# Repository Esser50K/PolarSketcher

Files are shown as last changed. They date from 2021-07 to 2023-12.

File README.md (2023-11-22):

# Polar Sketcher

The polar Sketcher is a somewhat compact robotic arm plotter.

The motivation is to have a somewhat simple and cheap design to create a 2D plotter.
It is also meant to not occupy a lot of space when idle as you don't need an entire XY CNC setup.

## Demo Video

Take a look a the journey of this build (without looking at commits)
https://youtu.be/corrBt9IMOM

## Upload PolarSketcherFirmware

The firmware of this project is designed to run on an esp32.
To upload the code from the command line run the following command from the `PolarSketcherFirmware` directory:
> platformio run --target upload --environment uno

You may want to change the `serial_port` option in the `platformio.ini` file. The current one is meant for the raspberrypi when using the GPIO serial connection.

To download platformio in the first place run:

`
curl -fsSL
     -o get-platformio.py
     https://raw.githubusercontent.com/platformio/platformio-core-installer/master/get-platformio.py
`

`python3 get-platformio.py`

## Optional software

There is a feature still in development to allow for the storing of drawings in order to pick up where you left off.
for this a local mongoDB is needed, for development se this to run mongodb locally:
> docker run -p 27017:27017 -v $PWD/mongodb:/data/db mongo:latest

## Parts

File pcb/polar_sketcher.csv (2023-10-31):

Id | Designator | Package | Quantity | Designation | Supplier and ref
1 | C2,C1 | CP_Radial_D8.0mm_P5.00mm | 2 | 100u
2 | A2,A1 | Pololu_Breakout-16_15.2x20.3mm | 2 | Pololu_Breakout_A4988
3 | R4,R2,R1,R3 | R_Axial_DIN0207_L6.3mm_D2.5mm_P7.62mm_Horizontal | 4 | 330
4 | J11 | PinHeader_1x05_P2.54mm_Vertical | 1 | ENCODER
5 | J5 | PinSocket_1x15_P2.54mm_Vertical | 1 | ESP_H_2
6 | J4 | PinSocket_1x15_P2.54mm_Vertical | 1 | ESP_H_1
7 | J8 | PinHeader_1x04_P2.54mm_Vertical | 1 | STEPPER_2
8 | J9 | PinHeader_1x02_P2.54mm_Vertical | 1 | MOTOR_POWER
9 | J3 | PinHeader_1x04_P2.54mm_Vertical | 1 | STEPPER_1
10 | J7 | PinHeader_1x02_P2.54mm_Vertical | 1 | LIMIT_4
11 | J6 | PinHeader_1x02_P2.54mm_Vertical | 1 | LIMIT_2
12 | J2 | PinHeader_1x02_P2.54mm_Vertical | 1 | LIMIT_3
13 | J1 | PinHeader_1x02_P2.54mm_Vertical | 1 | LIMIT_1
14 | J10 | PinHeader_1x03_P2.54mm_Vertical | 1 | SERVO_PINS

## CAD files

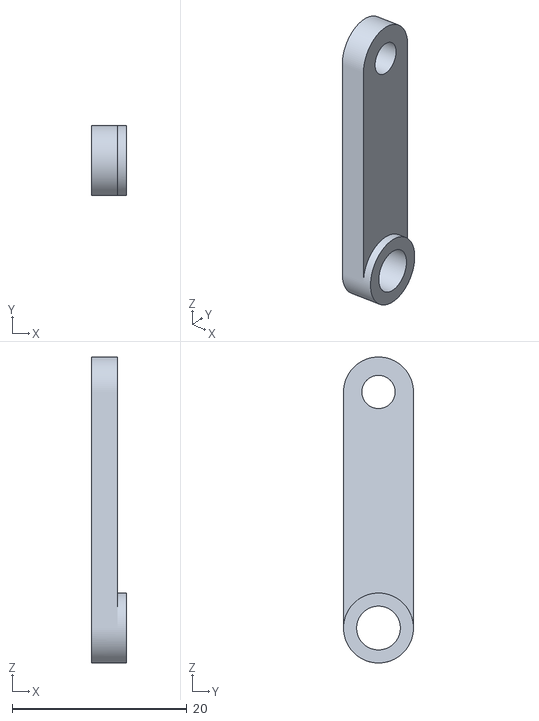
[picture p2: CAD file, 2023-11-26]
models/ServoLink2.stl
4.00 x 8.00 x 35.0

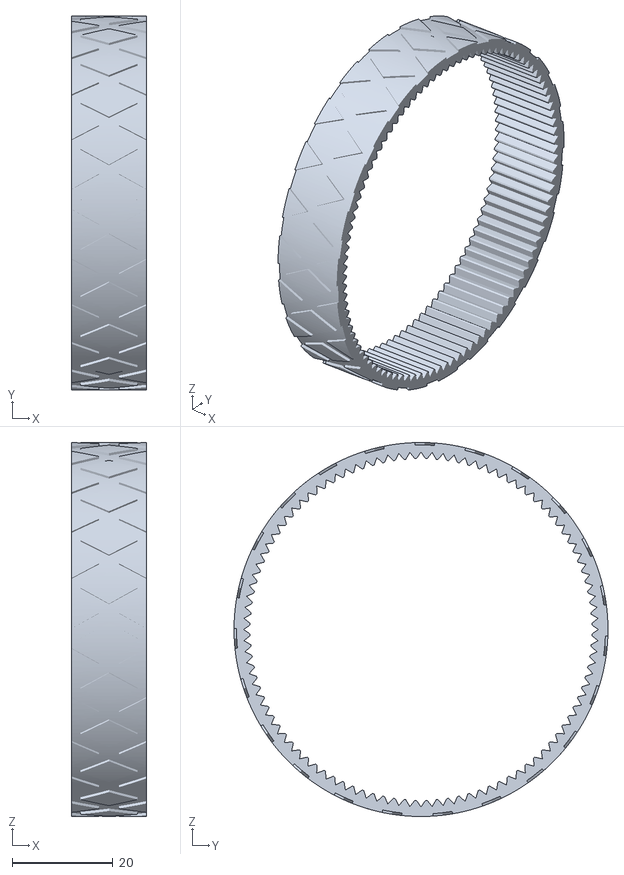
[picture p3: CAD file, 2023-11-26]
models/EndTire.stl
15.0 x 74.4 x 74.4

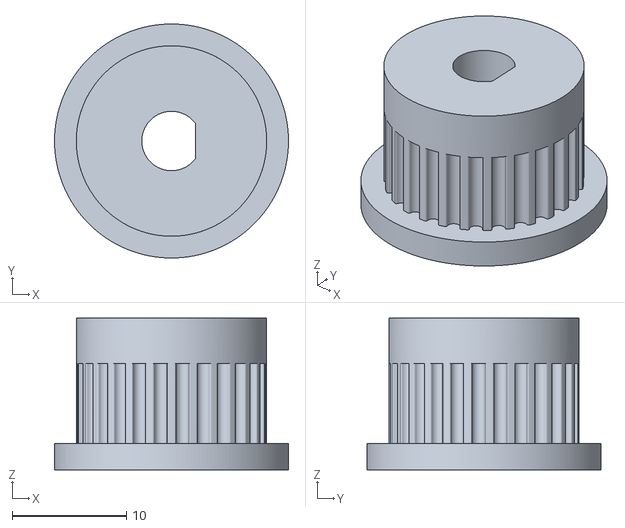
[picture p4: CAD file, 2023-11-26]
models/lil_pulley.stl
20.5 x 20.5 x 13.3

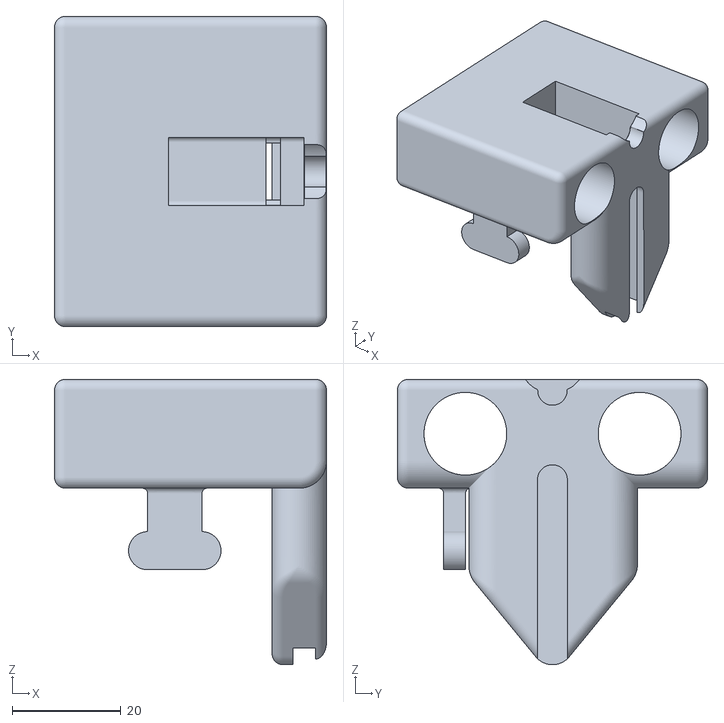
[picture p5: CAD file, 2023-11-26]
models/Carriage.stl
50.0 x 57.0 x 52.5

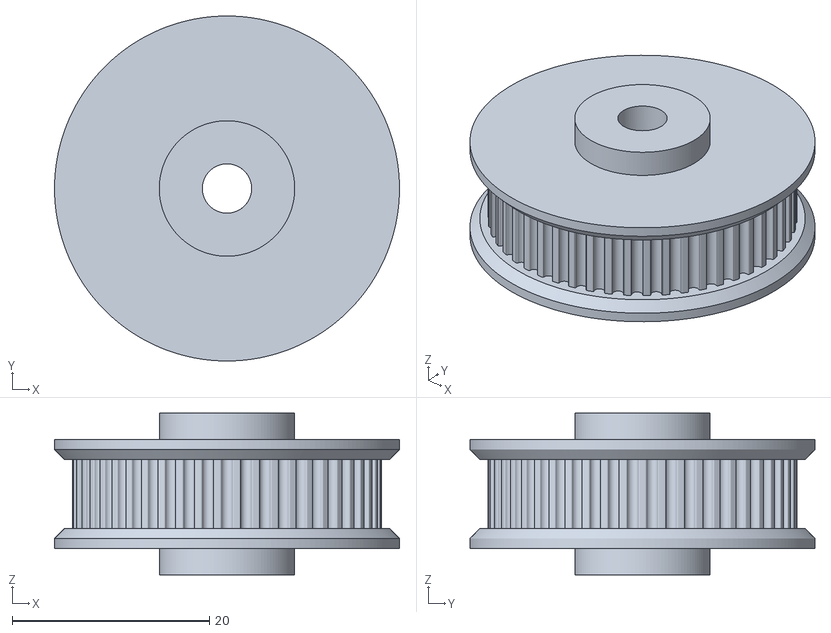
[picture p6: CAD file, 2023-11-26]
models/EndTensioner.stl
35.0 x 35.0 x 16.4

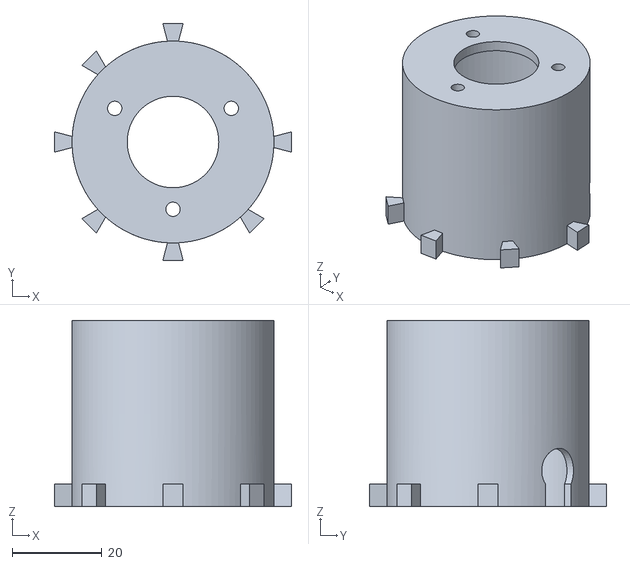
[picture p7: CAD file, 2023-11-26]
models/EncoderHousingTop.stl
52.8 x 52.8 x 41.5

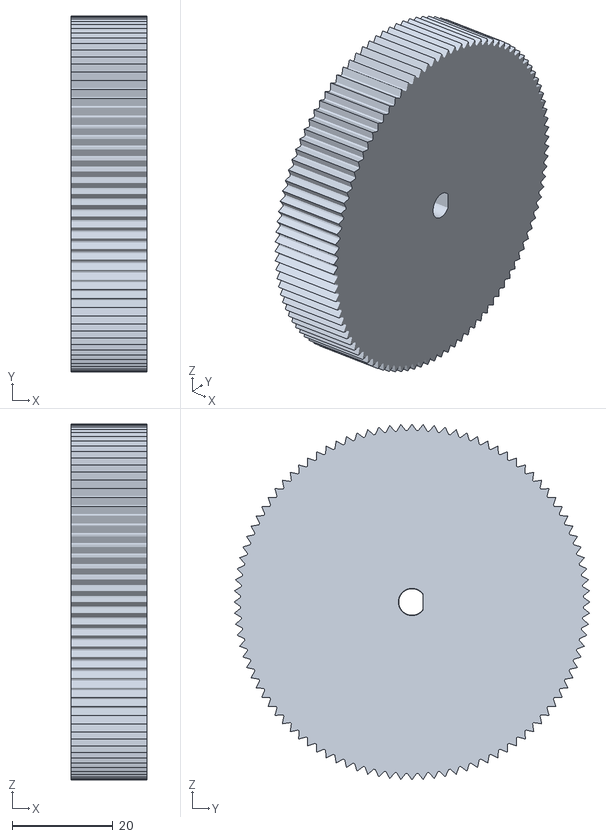
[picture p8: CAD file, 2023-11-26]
models/EndWheel.stl
15.0 x 70.6 x 70.6

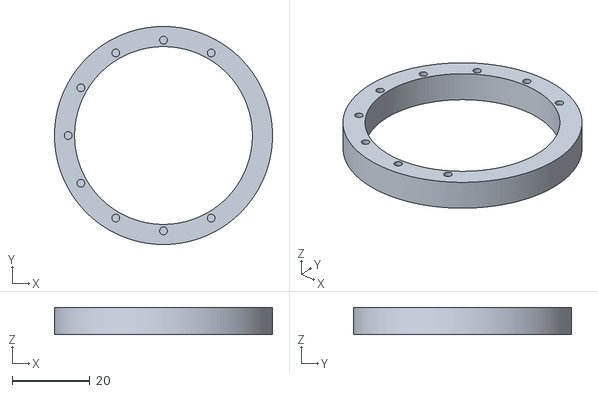
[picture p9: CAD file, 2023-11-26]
models/bottomBearingPart.stl
56.0 x 56.0 x 7.00

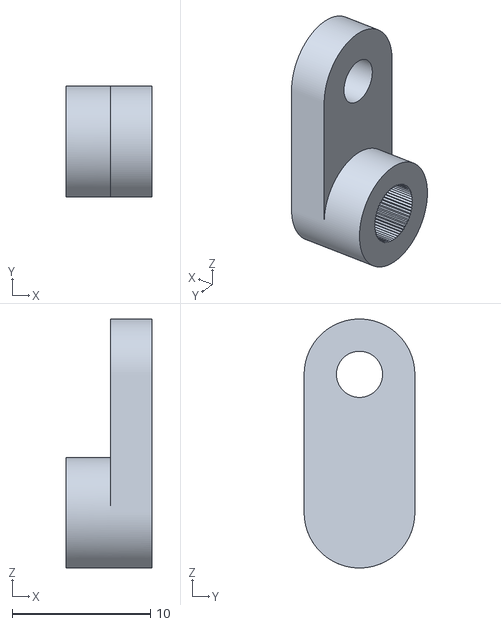
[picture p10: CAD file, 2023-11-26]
models/ServoLink1_tighter.stl
6.25 x 8.00 x 18.0

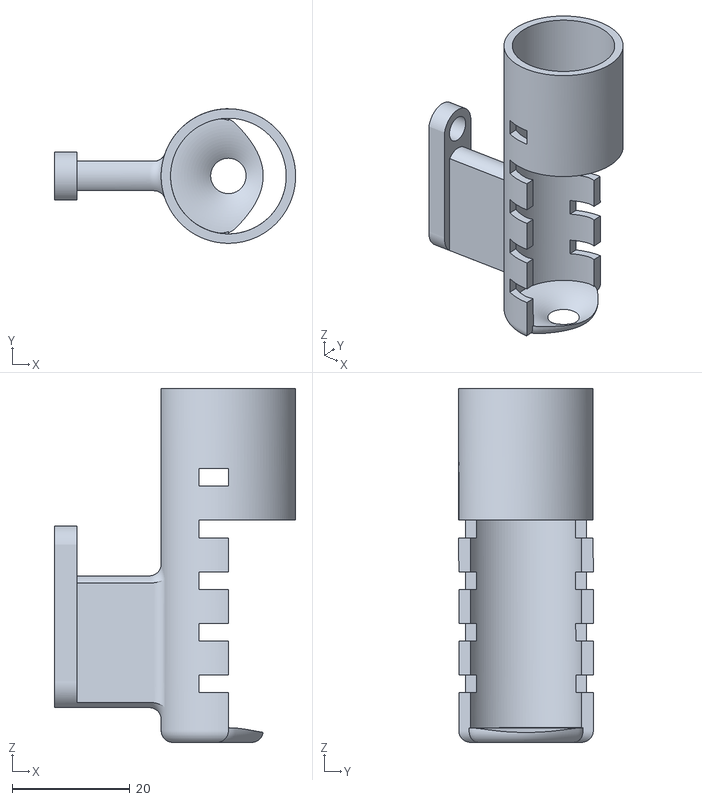
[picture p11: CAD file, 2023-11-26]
models/PenHolder.stl
40.9 x 22.8 x 60.0

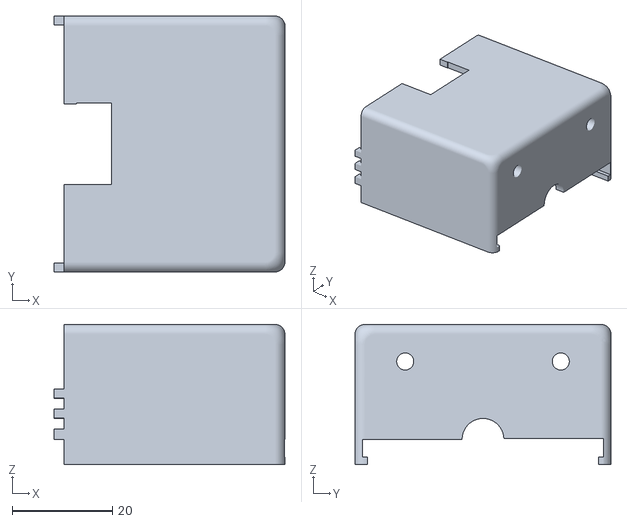
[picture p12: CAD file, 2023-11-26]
models/PlotterEndCloser.stl
46.0 x 51.0 x 28.0

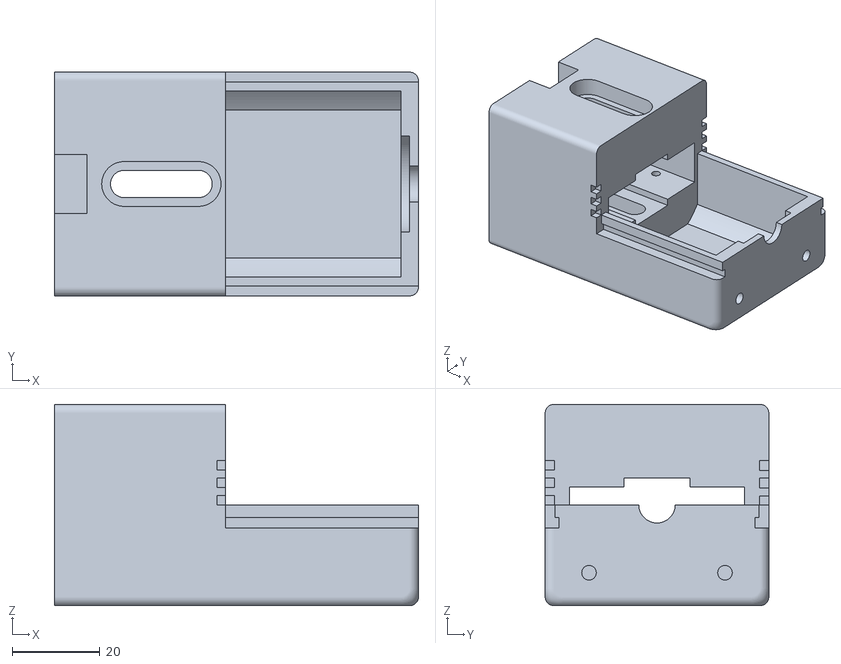
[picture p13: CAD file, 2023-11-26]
models/PlotterEnd.stl
83.0 x 51.0 x 45.9

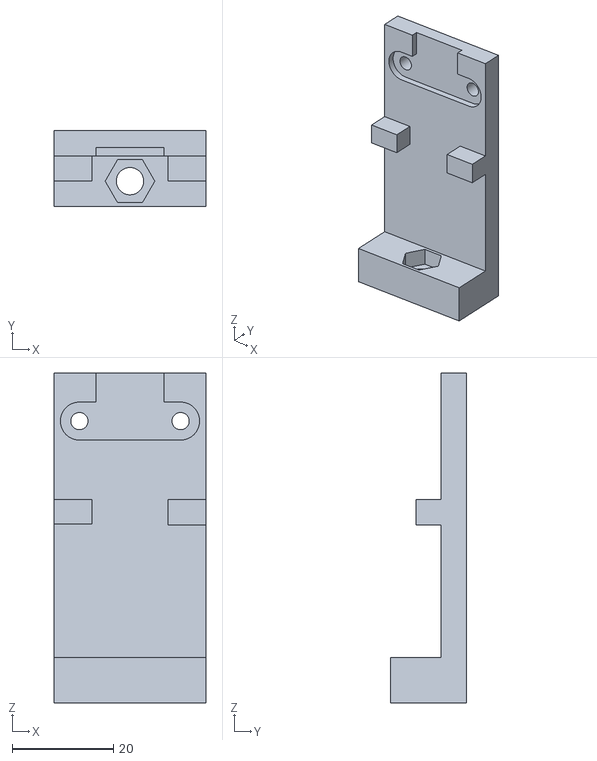
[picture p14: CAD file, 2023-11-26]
models/AngleLimitSwitch.stl
30.0 x 15.0 x 65.2

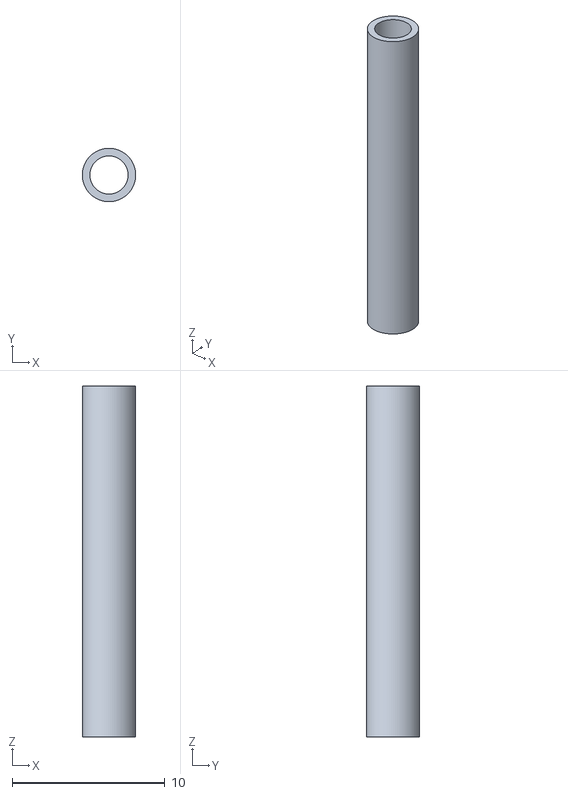
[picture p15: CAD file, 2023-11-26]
models/bearingShaft.stl
3.50 x 3.50 x 23.0

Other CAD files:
models/ServoLink1.stl
models/EncoderHousingBottom.stl
models/bearingTop.stl

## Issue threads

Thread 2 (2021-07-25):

Design Carriage

Esser50K, 2021-07-25:
Design the drawing device carriage

TODO:
- [ ] Design Pen Holder
- [ ] Design Platform
- [ ] Design Servo Holder
- [ ] Design Cable Management (servo and stepper)
- [ ] ?

Est. Effort: ?

Closed 2023-08-18.

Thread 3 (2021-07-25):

Design End of Arm

Esser50K, 2021-07-25:
Design the end of the arm that holds the Stepper motor and should have a belt tensioning mechanism.

TODO:
- [ ] Design Stepper Holder
- [ ] Design Belt Drive/Tensioner

Est. Effort: ?

Closed 2023-08-18.

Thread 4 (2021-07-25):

Design Beginning of Arm

Esser50K, 2021-07-25:
Design the beginning of the arm that holds the Stepper motor for the amplitude and should mount on top of a Potentiometer

TODO:
- [x] Design Belt Drive
- [x] Design Stepper Holder
- [ ] Design Limit Switch Holder
- [ ] Design Potentiometer Mounter

Est. Effort: ?

Closed 2023-08-18.

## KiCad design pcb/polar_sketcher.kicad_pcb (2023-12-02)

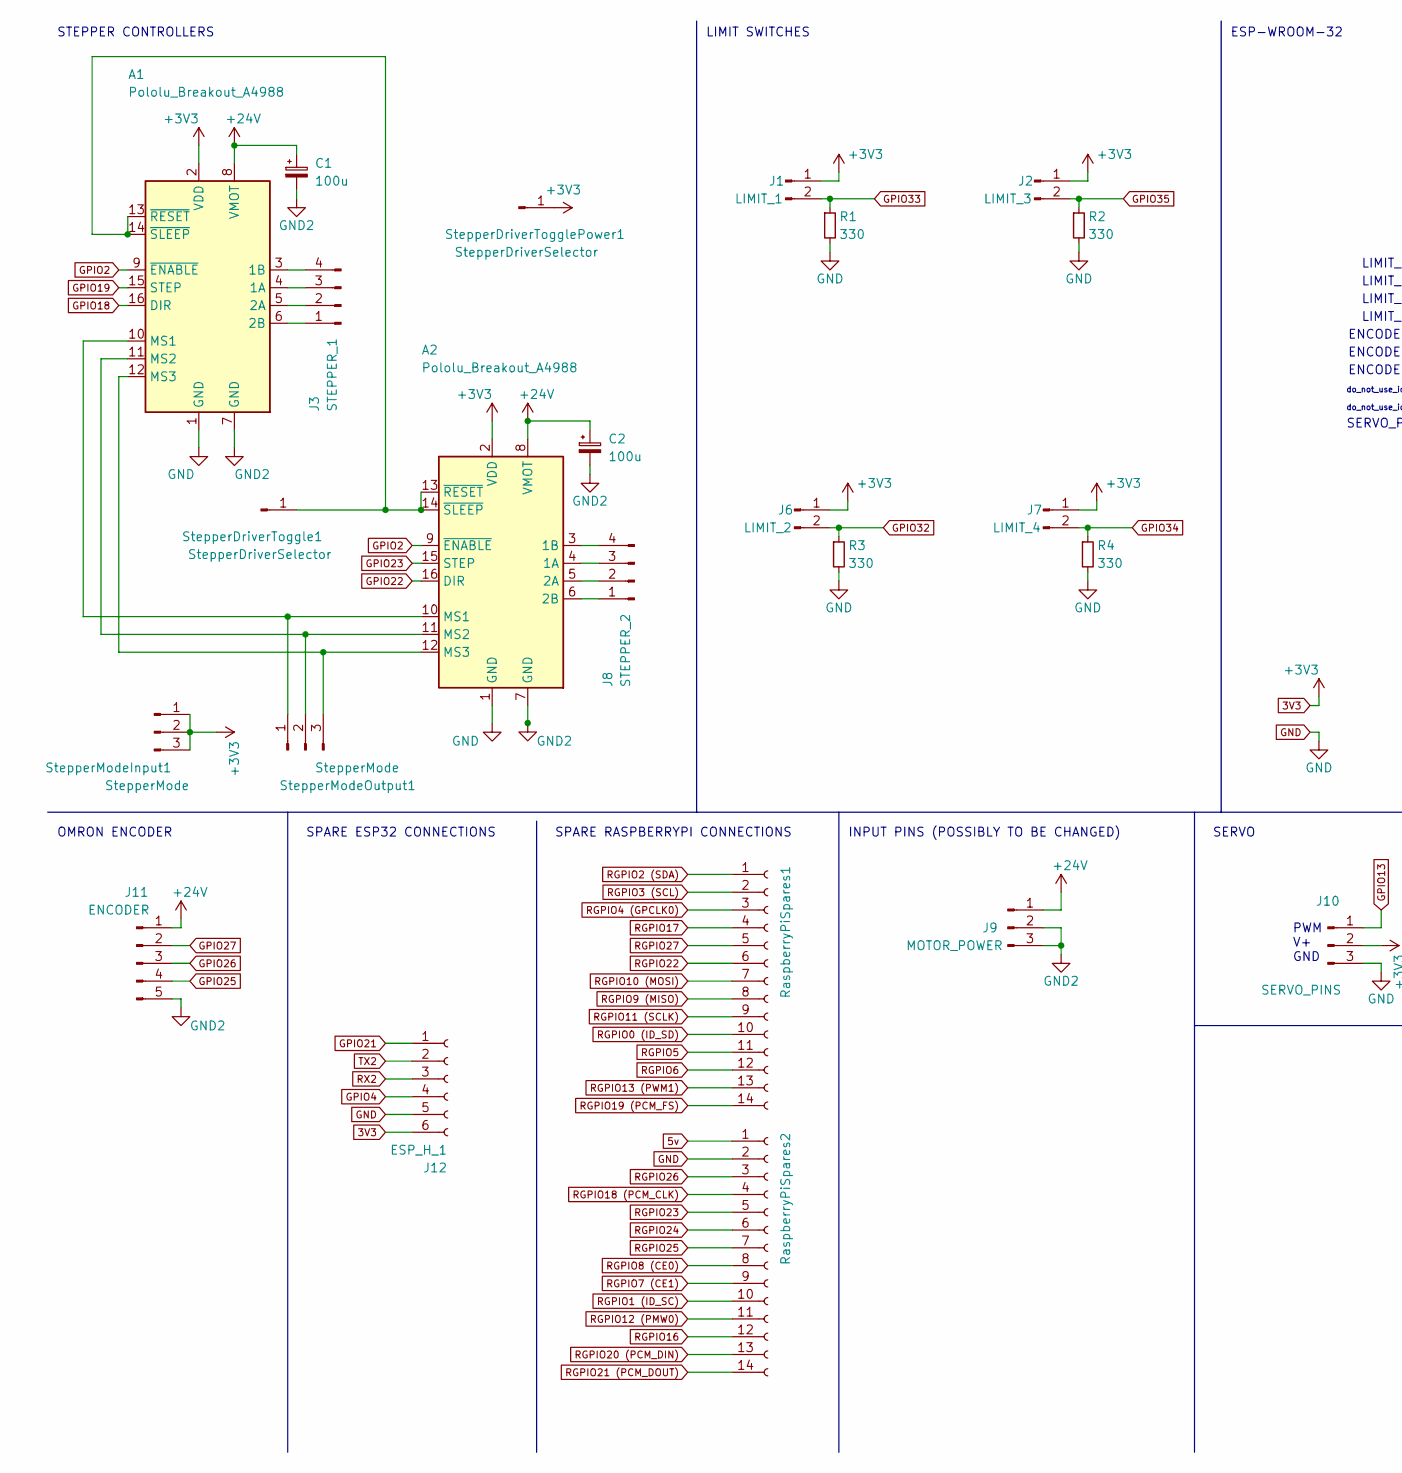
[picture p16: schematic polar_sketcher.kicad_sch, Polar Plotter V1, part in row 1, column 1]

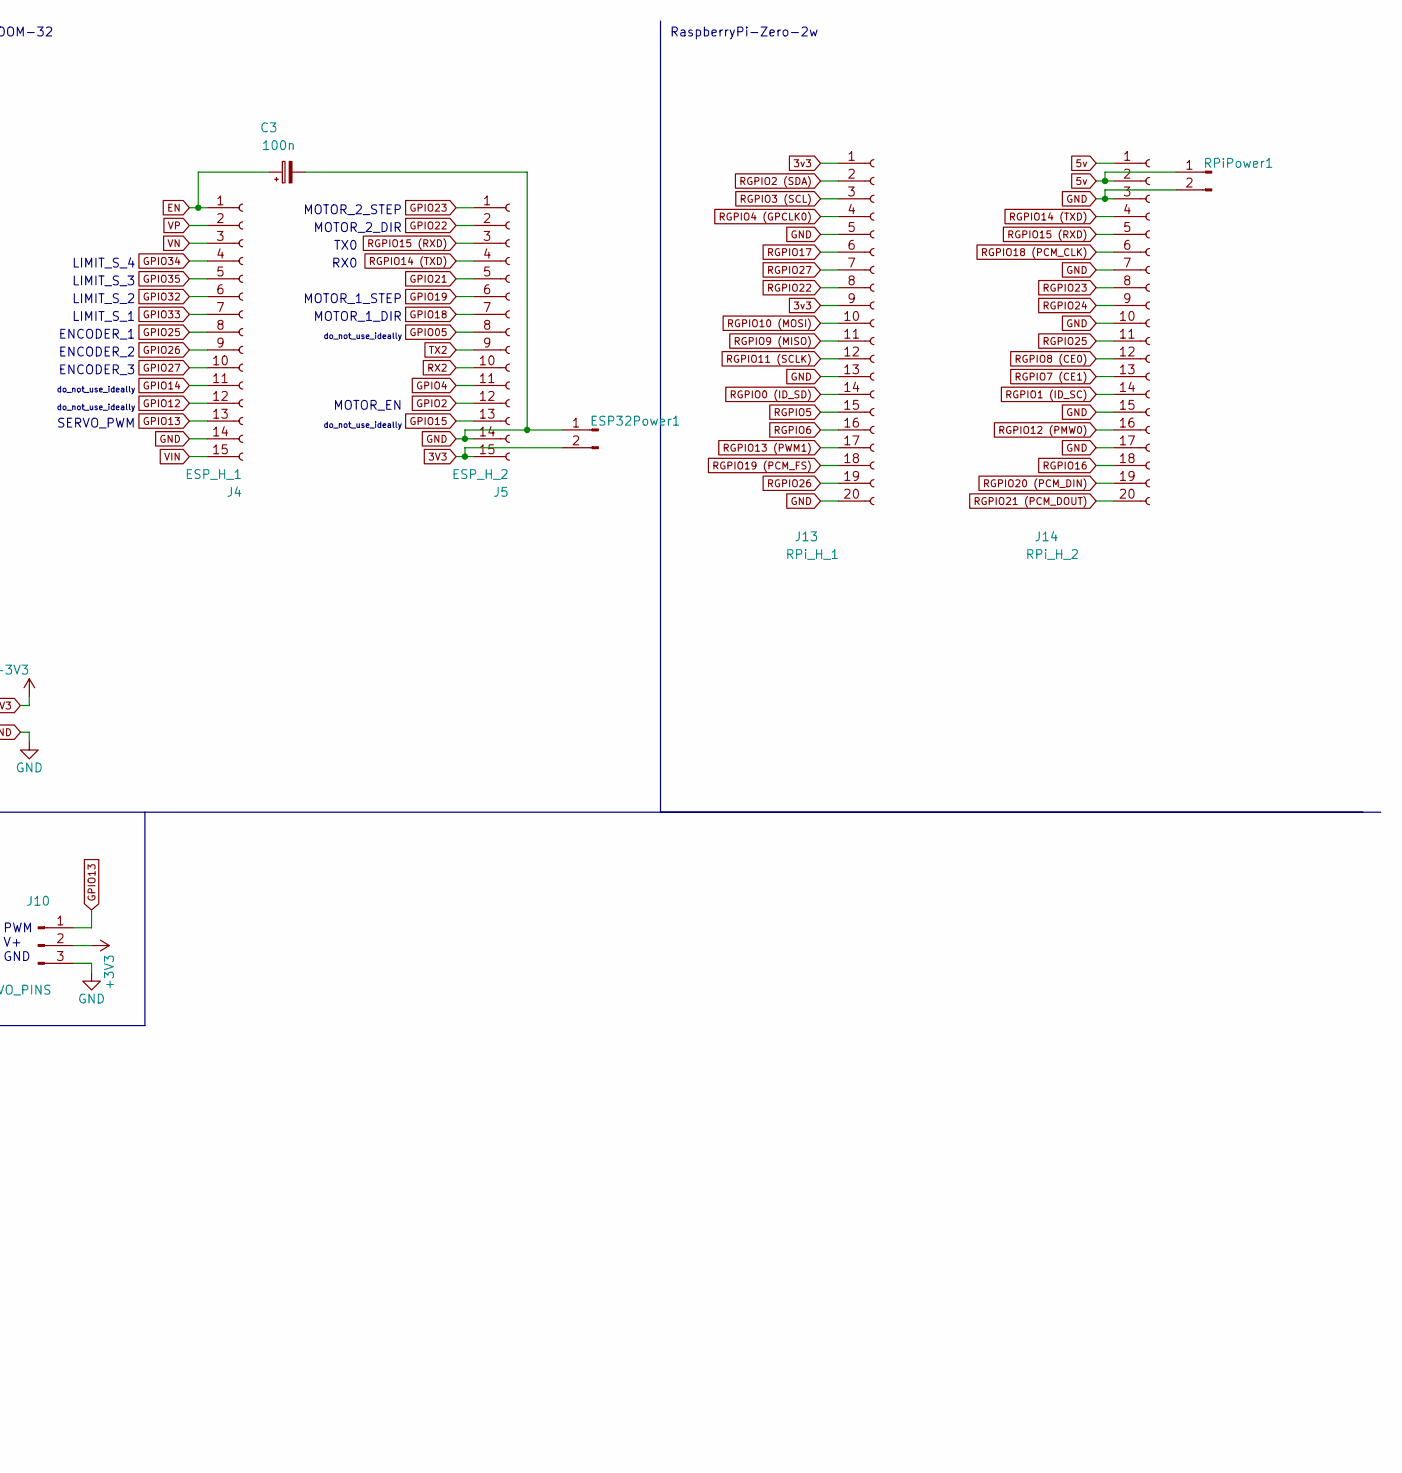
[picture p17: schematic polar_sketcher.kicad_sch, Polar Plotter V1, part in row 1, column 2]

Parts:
A1, A2: Pololu_Breakout_A4988; Pololu_Breakout-16_15.2x20.3mm
C1, C2: 100u; CP_Radial_D8.0mm_P5.00mm
C3: 100n; CP_Radial_D4.0mm_P2.00mm
ESP32Power1: V+; PinHeader_1x02_P2.54mm_Vertical
J1: LIMIT_1; PinHeader_1x02_P2.54mm_Vertical
J2: LIMIT_3; PinHeader_1x02_P2.54mm_Vertical
J3: STEPPER_1; PinHeader_1x04_P2.54mm_Vertical
J4: ESP_H_1; PinSocket_1x15_P2.54mm_Vertical
J5: ESP_H_2; PinSocket_1x15_P2.54mm_Vertical
J6: LIMIT_2; PinHeader_1x02_P2.54mm_Vertical
J7: LIMIT_4; PinHeader_1x02_P2.54mm_Vertical
J8: STEPPER_2; PinHeader_1x04_P2.54mm_Vertical
J9: MOTOR_POWER; PinHeader_1x03_P2.54mm_Vertical
J10: SERVO_PINS; PinHeader_1x03_P2.54mm_Vertical
J11: ENCODER; PinHeader_1x05_P2.54mm_Vertical
J12: ESP_H_1; PinSocket_1x06_P2.54mm_Vertical
J13: RPi_H_1; PinSocket_1x20_P2.54mm_Vertical
J14: RPi_H_2; PinSocket_1x20_P2.54mm_Vertical
R1, R2, R3, R4: 330; R_Axial_DIN0207_L6.3mm_D2.5mm_P7.62mm_Horizontal
RPiPower1: V+; PinHeader_1x02_P2.54mm_Vertical
RaspberryPiSpares1, RaspberryPiSpares2: RPi_H_1; PinSocket_1x14_P2.54mm_Vertical
StepperDriverToggle1: StepperDriverSelector; PinHeader_1x01_P2.54mm_Vertical
StepperDriverTogglePower1: StepperDriverSelector; PinHeader_1x01_P2.54mm_Vertical
StepperModeInput1: StepperMode; PinHeader_1x03_P2.54mm_Vertical
StepperModeOutput1: StepperMode; PinHeader_1x03_P2.54mm_Vertical

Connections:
3V3: A1.2 (VDD), A2.2 (VDD), ESP32Power1.2, J1.1, J2.1, J5.15, J6.1, J7.1, J10.2, J12.6, StepperDriverTogglePower1.1, StepperModeInput1.1, StepperModeInput1.2, StepperModeInput1.3
3v3: J13.1, J13.9
5v: J14.1, J14.2, RPiPower1.1, RaspberryPiSpares2.1
+24V: A1.8 (VMOT), A2.8 (VMOT), C1.1, C2.1, J9.1, J11.1
EN: C3.1, J4.1
GND: A1.1 (GND), A2.1 (GND), C3.2, ESP32Power1.1, J4.14, J5.14, J10.3, J12.5, J13.5, J13.13, J13.20, J14.3, J14.7, J14.10, J14.15, J14.17, R1.2, R2.2, R3.2, R4.2, RPiPower1.2, RaspberryPiSpares2.2
GND2: A1.7 (GND), A2.7 (GND), C1.2, C2.2, J9.2, J9.3, J11.5
GPIO2: A1.9 (~ENABLE), A2.9 (~ENABLE), J5.12
GPIO4: J5.11, J12.4
GPIO05: J5.8
GPIO12: J4.12
GPIO13: J4.13, J10.1
GPIO14: J4.11
GPIO15: J5.13
GPIO18: A1.16 (DIR), J5.7
GPIO19: A1.15 (STEP), J5.6
GPIO21: J5.5, J12.1
GPIO22: A2.16 (DIR), J5.2
GPIO23: A2.15 (STEP), J5.1
GPIO25: J4.8, J11.4
GPIO26: J4.9, J11.3
GPIO27: J4.10, J11.2
GPIO32: J4.6, J6.2, R3.1
GPIO33: J1.2, J4.7, R1.1
GPIO34: J4.4, J7.2, R4.1
GPIO35: J2.2, J4.5, R2.1
unnamed: A1.3 (1B), J3.4
unnamed: A1.4 (1A), J3.3
unnamed: A1.5 (2A), J3.2
unnamed: A1.6 (2B), J3.1
unnamed: A1.10 (MS1), A2.10 (MS1), StepperModeOutput1.1
unnamed: A1.11 (MS2), A2.11 (MS2), StepperModeOutput1.2
unnamed: A1.12 (MS3), A2.12 (MS3), StepperModeOutput1.3
unnamed: A1.13 (~RESET), A1.14 (~SLEEP), A2.13 (~RESET), A2.14 (~SLEEP), StepperDriverToggle1.1
unnamed: A2.3 (1B), J8.4
unnamed: A2.4 (1A), J8.3
unnamed: A2.5 (2A), J8.2
unnamed: A2.6 (2B), J8.1
RGPIO0 (ID_SD): J13.14, RaspberryPiSpares1.10
RGPIO1 (ID_SC): J14.14, RaspberryPiSpares2.10
RGPIO2 (SDA): J13.2, RaspberryPiSpares1.1
RGPIO3 (SCL): J13.3, RaspberryPiSpares1.2
RGPIO4 (GPCLK0): J13.4, RaspberryPiSpares1.3
RGPIO5: J13.15, RaspberryPiSpares1.11
RGPIO6: J13.16, RaspberryPiSpares1.12
RGPIO7 (CE1): J14.13, RaspberryPiSpares2.9
RGPIO8 (CE0): J14.12, RaspberryPiSpares2.8
RGPIO9 (MISO): J13.11, RaspberryPiSpares1.8
RGPIO10 (MOSI): J13.10, RaspberryPiSpares1.7
RGPIO11 (SCLK): J13.12, RaspberryPiSpares1.9
RGPIO12 (PMW0): J14.16, RaspberryPiSpares2.11
RGPIO13 (PWM1): J13.17, RaspberryPiSpares1.13
RGPIO14 (TXD): J5.4, J14.4
RGPIO15 (RXD): J5.3, J14.5
RGPIO16: J14.18, RaspberryPiSpares2.12
RGPIO17: J13.6, RaspberryPiSpares1.4
RGPIO18 (PCM_CLK): J14.6, RaspberryPiSpares2.4
RGPIO19 (PCM_FS): J13.18, RaspberryPiSpares1.14
RGPIO20 (PCM_DIN): J14.19, RaspberryPiSpares2.13
RGPIO21 (PCM_DOUT): J14.20, RaspberryPiSpares2.14
RGPIO22: J13.8, RaspberryPiSpares1.6
RGPIO23: J14.8, RaspberryPiSpares2.5
RGPIO24: J14.9, RaspberryPiSpares2.6
RGPIO25: J14.11, RaspberryPiSpares2.7
RGPIO26: J13.19, RaspberryPiSpares2.3
RGPIO27: J13.7, RaspberryPiSpares1.5
RX2: J5.10, J12.3
TX2: J5.9, J12.2
VIN: J4.15
VN: J4.3
VP: J4.2

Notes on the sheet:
do_not_use_ideally
SPARE ESP32 CONNECTIONS
MOTOR_2_STEP
LIMIT_S_2
RaspberryPi-Zero-2w
TX0
LIMIT_S_4
MOTOR_1_STEP
ENCODER_3
MOTOR_EN
LIMIT SWITCHES
OMRON ENCODER
MOTOR_1_DIR
ENCODER_2
SERVO_PWM
SERVO
ESP-WROOM-32
ENCODER_1
STEPPER CONTROLLERS
SPARE RASPBERRYPI CONNECTIONS
MOTOR_2_DIR
PWM V+ GND
LIMIT_S_1
RX0
LIMIT_S_3
INPUT PINS (POSSIBLY TO BE CHANGED)

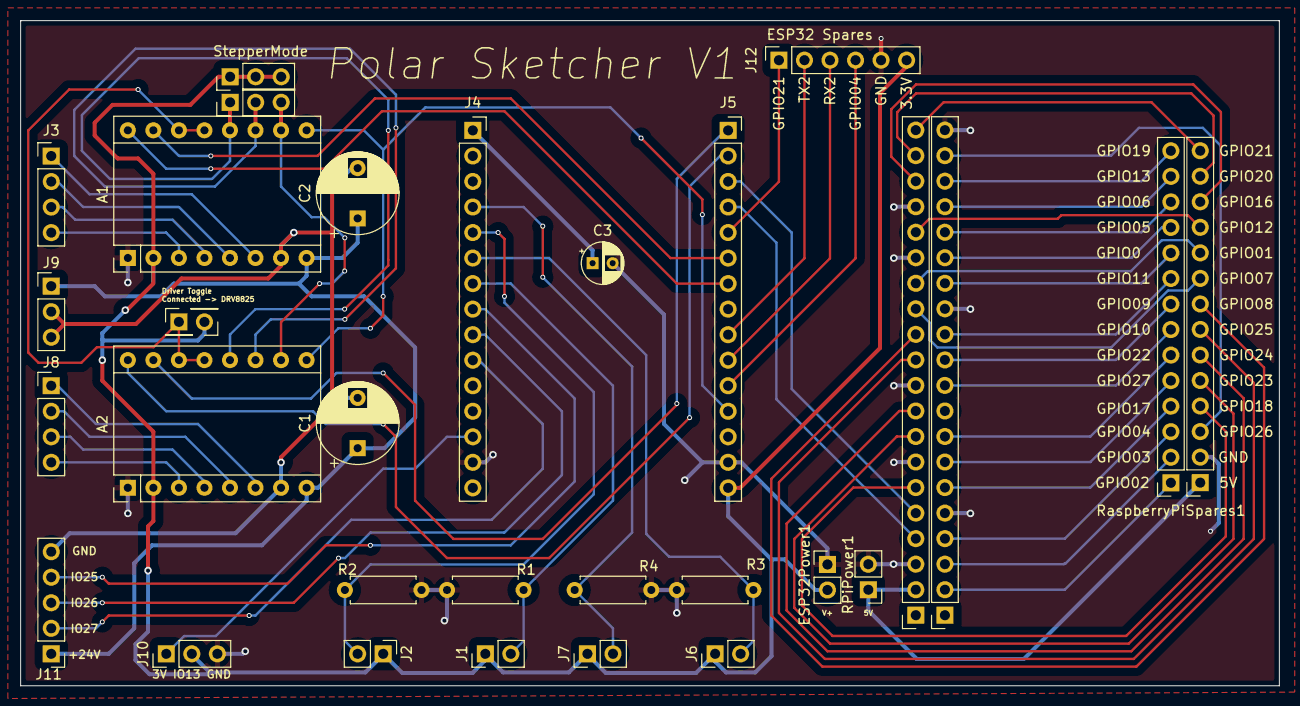
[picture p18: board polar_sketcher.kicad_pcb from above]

Board: 2 copper layers, 125.2 x 66.2 mm, 31 parts (0 on the bottom side), 64 nets.

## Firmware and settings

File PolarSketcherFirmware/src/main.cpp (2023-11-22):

#include "Stepper/Stepper.h"
#include "SerialUtils/SerialUtils.h"
#include <Arduino.h>
#include <ESP32Encoder.h>
#include <Servo.h>

// pins
const int enableStepper = 2;
const int angleStepPin = 19;
const int angleDirPin = 18;
const int amplitudeStepPin = 23;
const int amplitudeDirPin = 22;

const int zeroAnglePin = 32;
const int maxAnglePin = 33;
const int zeroAmplitudePin = 35;
const int maxAmplitudePin = 34;

const int encoderPhaseAPin = 27;
const int encoderPhaseBPin = 26;

const int penServoPin = 13;

const long BAUD_RATE = 115200;

// physical measurements
const int railLengthMm = 585;
const int penHolderRadiusMm = 12;
const int offsetMm = 25 + penHolderRadiusMm;
const int carriageLenghtMm = 84 - penHolderRadiusMm;
const int travelableDistanceMm = railLengthMm - offsetMm - carriageLenghtMm;

// max stepper positions
// will be filled by the controller and can be
// measured with the autoCalibrate function
long travelableDistanceSteps = 0;
float stepsPerMm = 0;
long minAmplitudePos = 0;
long maxAmplituePos = 0;
long maxAnglePos = 0;
long maxEncoderCount = 0;

// feature flags
bool angleCorrectionEnabled = false;

// declare steppers
Stepper *amplitudeStepper;
Stepper *angleStepper;

// declare encoder
ESP32Encoder angleEncoder;

// pen servo
Servo penServo;

// modes
int currentMode = 0;
enum mode
{
  idle,
  homing,
  autoCalibration,
  drawing
};

bool digitalReadCheck(int pin, int expected, int nChecks)
{
  int checks = 0;
  while (digitalRead(pin) == expected && checks < nChecks)
  {
    checks++;
  }

  // if it looped through it means that the result is consistently what we expect
  return checks == nChecks;
}

bool home()
{
  penServo.write(0);

  bool zeroAmplitudePressed = digitalRead(zeroAmplitudePin) == 1 ? false : true;
  bool zeroAnglePressed = digitalRead(zeroAnglePin) == 1 ? false : true;

  if (zeroAmplitudePressed)
  {
    amplitudeStepper->setPosition(minAmplitudePos);
    amplitudeStepper->setTargetPosition(minAmplitudePos);
  }
  else
  {
    amplitudeStepper->singleStepAtSpeed(false);
  }

  if (zeroAnglePressed)
  {
    // also reset encoder
    angleEncoder.setCount(0);
    angleStepper->setPosition(0);
    angleStepper->setTargetPosition(0);
  }
  else
  {
    angleStepper->singleStepAtSpeed(false);
  }

  // perform extra checks because of flaky reads
  int necessaryChecks = 5;
  return digitalReadCheck(zeroAmplitudePin, 0, necessaryChecks) && digitalReadCheck(zeroAnglePin, 0, necessaryChecks);
}

bool calibrated = false;
bool calibrating = false;
bool autoCalibrate()
{
  if (calibrated)
  {
    calibrated = false;
    travelableDistanceSteps = 0;
    stepsPerMm = 0;
    minAmplitudePos = 0;
    maxAmplituePos = 0;
    maxAnglePos = 0;
    maxEncoderCount = 0;
  }

  if (!calibrated && !calibrating && home())
  {
    calibrating = true;
  }

  if (!calibrating)
  {
    return false;
  }

  bool maxAmplitudePressed = digitalRead(maxAmplitudePin) == 1 ? false : true;
  bool maxAnglePressed = digitalRead(maxAnglePin) == 1 ? false : true;

  if (!maxAmplitudePressed)
    amplitudeStepper->singleStepAtSpeed(true);

  if (!maxAnglePressed)
    angleStepper->singleStepAtSpeed(true);

  // also check if stepsPerMm is 0, otherwise it has been calibrated already
  // do multi check here too, first check is for fastfail
  if (maxAmplitudePressed && digitalReadCheck(maxAmplitudePin, 0, 4) && stepsPerMm == 0)
  {
    travelableDistanceSteps = amplitudeStepper->getPosition();
    stepsPerMm = float(travelableDistanceSteps) / float(travelableDistanceMm);
    minAmplitudePos = long(offsetMm) * long(stepsPerMm);
    maxAmplituePos = travelableDistanceSteps + minAmplitudePos;

    amplitudeStepper->setPosition(maxAmplituePos);
    amplitudeStepper->setTargetPosition(maxAmplituePos);
  }

  if (maxAnglePressed && digitalReadCheck(maxAnglePin, 0, 4))
  {
    maxAnglePos = angleStepper->getPosition();
    angleStepper->setPosition(maxAnglePos);
    angleStepper->setTargetPosition(maxAnglePos);
    // also set the encoder max
    maxEncoderCount = angleEncoder.getCount();
  }

  if ((maxAmplitudePressed && maxAnglePressed) &&
      (digitalReadCheck(maxAnglePin, 0, 4) && digitalReadCheck(maxAmplitudePin, 0, 4)))
  {
    maxAmplituePos = amplitudeStepper->getPosition();
    maxAnglePos = angleStepper->getPosition();
    maxEncoderCount = angleEncoder.getCount();
    calibrating = false;
    calibrated = true;
    return true;
  }

  return false;
}

long encoderPosToAnglePos()
{
  return map(angleEncoder.getCount(), 0, maxEncoderCount, 0, maxAnglePos);
}

long anglePosToEncoderPos(long stepperPos)
{
  return map(stepperPos, 0, maxAnglePos, 0, maxEncoderCount);
}

struct position
{
  long amplitudePosition;
  long anglePosition;
  long penPosition;
  long amplitudeVelocity;
  long angleVelocity;
};

int ledVal = HIGH;
const int futurePositionsLength = 1000;
int previousPosition = 0;
int nextPositionToPlace = 1;
int nextPositionToGo = 0;
position futurePositions[futurePositionsLength];

int stepsSinceCorrection = 0;
const int stepsUntilCorrection = 50;
bool angleTargetReached = false;
bool adjustingAnglePos = false;
const float compensationRatio = .1; // how much of the stepsDiff to compensate for on every position
int currentStepsDiff = 0;

void loadNewPosition()
{
  // check if we have a new position to go to
  int potentialNextPositionToGo = (nextPositionToGo + 1) % futurePositionsLength;
  if (potentialNextPositionToGo == nextPositionToPlace)
  {
    return;
  }

  // set new target
  nextPositionToGo = potentialNextPositionToGo;
  position nextPosition = futurePositions[nextPositionToGo];
  amplitudeStepper->setTargetPosition(nextPosition.amplitudePosition);

  int angleStepsCompensation = currentStepsDiff * compensationRatio;
  angleStepper->setTargetPosition(nextPosition.anglePosition + angleStepsCompensation);
  amplitudeStepper->setSpeed(nextPosition.amplitudeVelocity);
  angleStepper->setSpeed(nextPosition.angleVelocity);

  angleTargetReached = false;
  adjustingAnglePos = false;

  // put pen in position
  // the +1 is just because the .read()
  // returns the last value we wrote -1 ¯\_(ツ)_/¯
  // if (penServo.read() + 1 != nextPosition.penPosition)
  if (abs(nextPosition.penPosition - penServo.read()) > 2)
  {
    penServo.write(nextPosition.penPosition);
    // without this delay the plotter starts
    // moving before the pen has reached the bottom
    delay(150);
  }
}

bool targetAngleReached()
{
  if (!angleCorrectionEnabled)
  {
    return true;
  }

  long encoderAnglePos = encoderPosToAnglePos();
  float stepsPerEncoderUnit = maxAnglePos / float(maxEncoderCount);
  long positionDiff = encoderAnglePos - angleStepper->getPosition();
  if (angleCorrectionEnabled && positionDiff > (stepsPerEncoderUnit / 2))
  {
    return false;
  }

  return true;
}

bool adjustAngle()
{
  long encoderTargetPos = anglePosToEncoderPos(angleStepper->getTargetPosition());
  long encoderPosition = angleEncoder.getCount();

  if (encoderPosition != encoderTargetPos)
  {
    bool goingForward = encoderPosition < encoderTargetPos;
    bool stepped = angleStepper->singleStepAtSpeed(goingForward);
  }
  else
  {
    adjustingAnglePos = false;
    long encoderAnglePos = encoderPosToAnglePos();
    angleStepper->setPosition(encoderAnglePos);
    angleStepper->setTargetPosition(encoderAnglePos);
    return true;
  }

  return false;
}

bool incrementalAngleAdjust()
{
  long encoderTargetPos = anglePosToEncoderPos(angleStepper->getTargetPosition());
  long encoderPosition = angleEncoder.getCount();
  float stepsPerEncoderUnit = maxAnglePos / float(maxEncoderCount);
  return true;
}

bool correctAngle()
{
  if (!adjustingAnglePos)
  {
    if (targetAngleReached())
    {
      return true;
    }

    adjustingAnglePos = true;
    return false;
  }
  else
  {
    // return adjustAngle();
    return incrementalAngleAdjust();
  }
}

bool draw()
{
  // step toward target
  if ((amplitudeStepper->getPosition() != amplitudeStepper->getTargetPosition() ||
       angleStepper->getPosition() != angleStepper->getTargetPosition()) &&
      !adjustingAnglePos)
  {
    amplitudeStepper->stepTowardTarget();
    angleStepper->stepTowardTarget();
  }
  else if (!angleTargetReached)
  {
    // angle position correction routine
    angleTargetReached = correctAngle();
    if (angleTargetReached)
    {
      loadNewPosition();
    }
  }
  else
  {
    loadNewPosition();
  }

  return false;
}

void printStatus()
{
  serialWriteln("STATUS START");
  serialWriteln(currentMode);
  serialWriteln(calibrated);
  serialWriteln(calibrating);

  serialWriteln(amplitudeStepper->getPosition());
  serialWriteln(amplitudeStepper->getTargetPosition());
  serialWriteln(amplitudeStepper->getCurrentSpeed());

  serialWriteln(angleStepper->getPosition());
  serialWriteln(angleStepper->getTargetPosition());
  serialWriteln(angleStepper->getCurrentSpeed());

  serialWriteln(travelableDistanceSteps);
  serialWriteln(stepsPerMm);
  serialWriteln(minAmplitudePos);
  serialWriteln(maxAmplituePos);
  serialWriteln(maxAnglePos);
  serialWriteln(angleEncoder.getCount());
  serialWriteln(maxEncoderCount);
  serialWriteln(nextPositionToPlace);
  serialWriteln(nextPositionToGo);

  serialWriteln(digitalRead(zeroAmplitudePin));
  serialWriteln(digitalRead(maxAmplitudePin));
  serialWriteln(digitalRead(zeroAnglePin));
  serialWriteln(digitalRead(maxAnglePin));

  serialWriteln(angleCorrectionEnabled);
}

enum command
{
  none,
  getStatus,
  setMode,
  calibrate,
  addPosition,
  setAngleCorrection,
};

int readInt()
{
  return Serial.read() + (Serial.read() << 8) + (Serial.read() << 16) + (Serial.read() << 24);
}

float readFloat()
{
  float f;
  Serial.readBytes((char *)&f, 4);
  return f;
}

int intFromBuffer(const char *buffer, int position)
{
  int value = 0;
  // for (int i = 0; i < 4; i++) {
  //     value += (buffer[position + i] << (i * 8));
  // }
  memcpy(&value, buffer + position, sizeof(int));
  return value;
}

float floatFromBuffer(const char *buffer, int position)
{
  float value = 0;
  memcpy(&value, buffer + position, sizeof(float));
  return value;
}

const int nMessageDelimiters = 3;
bool commandStarted = false;
bool commandComplete = false;

int commandDelimiterCounter = 0;
char commandStartChar = '<';
char commandEndChar = '>';

int commandBufferIdx = 0;
char currentCommand = 0;
char commandBuffer[100];

int received_checksum = 0;
int calculated_checksum = 0;
bool parseCommand()
{
  int readIdx = 0;
  int cmd = intFromBuffer(commandBuffer, readIdx);
  readIdx += sizeof(cmd);

  // not allowed to be initialised inside of switch statement
  int enableAngleCorrection = 0;
  switch (cmd)
  {
  case setMode:
    currentMode = intFromBuffer(commandBuffer, readIdx);
    break;
  case getStatus:
    printStatus();
    break;
  case setAngleCorrection:
    enableAngleCorrection = intFromBuffer(commandBuffer, readIdx);
    angleCorrectionEnabled = enableAngleCorrection > 0;
    break;
  case calibrate:
    travelableDistanceSteps = intFromBuffer(commandBuffer, readIdx);
    stepsPerMm = floatFromBuffer(commandBuffer, readIdx + 4);
    minAmplitudePos = intFromBuffer(commandBuffer, readIdx + 8);
    maxAmplituePos = intFromBuffer(commandBuffer, readIdx + 12);
    maxAnglePos = intFromBuffer(commandBuffer, readIdx + 16);
    maxEncoderCount = intFromBuffer(commandBuffer, readIdx + 20);

    amplitudeStepper->setPosition(minAmplitudePos);
    amplitudeStepper->setTargetPosition(minAmplitudePos);
    calibrated = true;
    break;
  case addPosition:
    if (nextPositionToGo == nextPositionToPlace)
    {
      return false;
    }

    position p;
    p.amplitudePosition = intFromBuffer(commandBuffer, readIdx);
    p.anglePosition = intFromBuffer(commandBuffer, readIdx + 4);
    p.penPosition = intFromBuffer(commandBuffer, readIdx + 8);
    p.amplitudeVelocity = intFromBuffer(commandBuffer, readIdx + 12);
    p.angleVelocity = intFromBuffer(commandBuffer, readIdx + 16);

    received_checksum = intFromBuffer(commandBuffer, readIdx + 20);
    calculated_checksum += (p.amplitudePosition % 123);
    calculated_checksum += (p.anglePosition % 123);
    calculated_checksum += (p.penPosition % 123);
    calculated_checksum += (p.amplitudeVelocity % 123);
    calculated_checksum += (p.angleVelocity % 123);

    if (received_checksum != calculated_checksum)
    {
      calculated_checksum = 0;
      return false;
    }

    futurePositions[nextPositionToPlace] = p;
    nextPositionToPlace = (nextPositionToPlace + 1) % futurePositionsLength;
    calculated_checksum = 0;
    break;
  default:
    serialWriteln("DID NOT RECOGNIZE COMMAND TYPE");
  }

  calculated_checksum = 0;
  return true;
}

void readInput()
{
  if (!Serial.available() && !commandComplete)
  {
    return;
  }

  char c = Serial.read();

  // look for start of message
  if (!commandStarted)
  {
    if (c == commandStartChar)
    {
      commandDelimiterCounter++;
      // serialWriteln("GOT START DELIMITER");
      if (commandDelimiterCounter == nMessageDelimiters)
      {
        commandStarted = true;
        commandDelimiterCounter = 0;
        // serialWriteln("COMMAND STARTED");
      }
    }
  }
  else if (commandStarted && !commandComplete)
  {
    // look for end of message
    if (c == commandEndChar)
    {
      commandDelimiterCounter++;
      if (commandDelimiterCounter == nMessageDelimiters)
      {
        commandComplete = true;
        // serialWriteln("COMMAND READ " + String(commandComplete));
      }
    }
    else
    {
      if (commandDelimiterCounter > 0)
      {
        // this means a previous byte was misinterpreted as an end delimiter
        for (int i = 0; i < commandDelimiterCounter; i++)
        {
          commandBuffer[commandBufferIdx + i] = commandEndChar;
          commandBufferIdx++;
        }
        commandDelimiterCounter = 0;
      }
      // serialWriteln("GOT COMMAND CHAR " + String(c));
      commandBuffer[commandBufferIdx] = c;
      commandBufferIdx++;
    }
  }
  else if (commandComplete)
  {
    // serialWriteln("PROCESSING CMD");
    if (parseCommand())
    {
      serialWriteln("OK");
    }
    else
    {
      serialWriteln("FAIL");
    }
    commandStarted = false;
    commandComplete = false;
    commandBufferIdx = 0;
    commandDelimiterCounter = 0;
  }
}

void enableMotors(bool enabled)
{
  uint8_t val = enabled ? LOW : HIGH; // enable is LOW
  digitalWrite(enableStepper, val);
}

void setup()
{
  Serial.setTxBufferSize(2048);
  Serial.setRxBufferSize(2048);
  Serial.begin(BAUD_RATE);

  // configure output pins
  pinMode(enableStepper, OUTPUT);
  pinMode(amplitudeStepPin, OUTPUT);
  pinMode(amplitudeDirPin, OUTPUT);
  pinMode(angleStepPin, OUTPUT);
  pinMode(angleDirPin, OUTPUT);

  // configure limit switches
  pinMode(zeroAmplitudePin, INPUT);
  pinMode(maxAmplitudePin, INPUT);
  pinMode(zeroAnglePin, INPUT);
  pinMode(maxAnglePin, INPUT);

  // enable and create steppers
  enableMotors(false);
  amplitudeStepper = new Stepper(amplitudeStepPin, amplitudeDirPin);
  angleStepper = new Stepper(angleStepPin, angleDirPin);

  // configure encoder
  ESP32Encoder::useInternalWeakPullResistors = UP;
  angleEncoder.always_interrupt = true;
  angleEncoder.attachFullQuad(encoderPhaseAPin, encoderPhaseBPin);
  angleEncoder.setCount(0);

  // attach servo
  penServo.attach(penServoPin);
  penServo.write(0);

  serialWriteln("SETUP DONE");
}

long idleStartTime = millis();
void loop()
{
  readInput();
  sendOutput();

  switch (currentMode)
  {
  case idle:
    if (millis() - idleStartTime > 10000)
    {
      enableMotors(false);
    }
    break;
  case homing:
    enableMotors(true);
    amplitudeStepper->setSpeed(3500);
    angleStepper->setSpeed(1200);
    if (home())
    {
      currentMode = idle;
      idleStartTime = millis();
    }
    break;
  case autoCalibration:
    enableMotors(true);
    if (!calibrating)
      stepsPerMm = 0;
    amplitudeStepper->setSpeed(3500);
    angleStepper->setSpeed(1200);
    if (autoCalibrate())
      currentMode = homing;
    break;
  case drawing:
    enableMotors(true);
    if (draw())
    {
      currentMode = idle;
      idleStartTime = millis();
    }
    break;
  default:
    currentMode = idle;
    idleStartTime = millis();

    break;
  }
}

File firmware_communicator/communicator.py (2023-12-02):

import os
import time
import serial
import struct
from enum import Enum
from threading import Thread, Event

CMD_PROCESSED_SUCCESSFULLY_MSG = "OK"
CMD_PROCESSING_FAILURE_MSG = "FAIL"
SETUP_DONE_MSG = "SETUP DONE"
STATUS_START_MSG = "STATUS START"
UNRECOGNIZED_CMD_MSG = "DID NOT RECOGNIZE COMMAND TYPE"
CHECKSUM_MISMATCH = "CHECKSUM MISMATCH"
CMD_PROCESSED_EVENT = Event()


class Mode(Enum):
    IDLE = 0
    HOME = 1
    AUTO_CALIBRATE = 2
    DRAW = 3


class Command(Enum):
    NONE = 0
    GET_STATUS = 1
    SET_MODE = 2
    CALIBRATE = 3
    ADD_POSITION = 4


class Status:
    def __init__(self):
        self.currentMode = Mode.IDLE
        self.calibrated = False
        self.calibrating = False
        self.amplitudeStepperPos = 0
        self.amplitudeStepperTargetPos = 0
        self.amplitudeStepperSpeed = 0
        self.angleStepperPos = 0
        self.angleStepperTargetPos = 0
        self.angleStepperSpeed = 0
        self.travelableDistanceSteps = 0
        self.stepsPerMm = 0
        self.minAmplitudePos = 0
        self.maxAmplituePos = 0
        self.maxAnglePos = 0
        self.maxEncoderCount = 0
        self.nextPosToPlaceIdx = 0
        self.nextPosToGoIdx = 0
        self.minAmplitudeButtonPressed = 0
        self.maxAmplitudeButtonPressed = 0
        self.minAngleButtonPressed = 0
        self.maxAngleButtonPressed = 0

    def update_status(self, serial_conn: serial.Serial):
        self.currentMode = Mode(int(serial_conn.readline()))
        self.calibrated = False if int(serial_conn.readline()) == 0 else True
        self.calibrating = False if int(serial_conn.readline()) == 0 else True

        self.amplitudeStepperPos = int(serial_conn.readline())
        self.amplitudeStepperTargetPos = int(serial_conn.readline())
        self.amplitudeStepperSpeed = int(serial_conn.readline())

        self.angleStepperPos = int(serial_conn.readline())
        self.angleStepperTargetPos = int(serial_conn.readline())
        self.angleStepperSpeed = int(serial_conn.readline())

        self.travelableDistanceSteps = int(serial_conn.readline())
        self.stepsPerMm = float(serial_conn.readline())
        self.minAmplitudePos = int(serial_conn.readline())
        self.maxAmplituePos = int(serial_conn.readline())
        self.maxAnglePos = int(serial_conn.readline())
        self.encoderCount = int(serial_conn.readline())
        self.maxEncoderCount = int(serial_conn.readline())
        self.nextPosToPlaceIdx = int(serial_conn.readline())
        self.nextPosToGoIdx = int(serial_conn.readline())

        self.minAmplitudeButtonPressed = int(serial_conn.readline())
        self.maxAmplitudeButtonPressed = int(serial_conn.readline())
        self.minAngleButtonPressed = int(serial_conn.readline())
        self.maxAngleButtonPressed = int(serial_conn.readline())

    def __str__(self) -> str:
        out_str = ""
        out_str += "Current Mode: %s\n" % self.currentMode
        out_str += "Calibrated: %s\n" % self.calibrated
        out_str += "Calibrating: %s\n" % self.calibrating
        out_str += "Amplitude Pos: %s\n" % self.amplitudeStepperPos
        out_str += "Amplitude Target Pos: %s\n" % self.amplitudeStepperTargetPos
        out_str += "Amplitude Speed: %s\n" % self.amplitudeStepperSpeed
        out_str += "Angle Pos: %s\n" % self.angleStepperPos
        out_str += "Angle Target Pos: %s\n" % self.angleStepperTargetPos
        out_str += "Angle Speed: %s\n" % self.angleStepperSpeed
        out_str += "Travelable Distance Steps: %s\n" % self.travelableDistanceSteps
        out_str += "Steps per mm: %s\n" % self.stepsPerMm
        out_str += "Min amplitude Pos: %s\n" % self.minAmplitudePos
        out_str += "Max amplitude Pos: %s\n" % self.maxAmplituePos
        out_str += "Max angle Pos: %s\n" % self.maxAnglePos
        out_str += "Encoder Count: %s\n" % self.encoderCount
        out_str += "Max Encoder Count: %s\n" % self.maxEncoderCount
        out_str += "Next Pos To Place Idx: %s\n" % self.nextPosToPlaceIdx
        out_str += "Next Pos To Go Idx: %s\n" % self.nextPosToGoIdx
        out_str += "Min Amplitude Pressed: %s\n" % self.minAmplitudeButtonPressed
        out_str += "Max Amplitude Pressed: %s\n" % self.maxAmplitudeButtonPressed
        out_str += "Min Angle Pressed: %s\n" % self.minAngleButtonPressed
        out_str += "Max Angle Pressed: %s\n" % self.maxAngleButtonPressed

        return out_str


def get_calib_msg():
    msg = b''
    # travelable distance steps
    msg += encode_int(74810)

    # steps per mm
    msg += encode_float(157.16)

    # minAmplitudePos
    msg += encode_int(5809)

    # maxAmplituePos
    msg += encode_int(80619)

    # maxAnglePos
    msg += encode_int(28760)

    # maxEncoderCount
    msg += encode_int(2450)

    for i, c in enumerate(msg):
        print(i + 4, ":", c)
    print(msg, len(msg))
    return msg


def read_from_serial(connection: serial.Serial):
    received = b''
    while True:
        try:
            connection.timeout = 1
            received += connection.read()
            if not received.endswith(b'\n'):
                continue

            line = received.split(b'\n')[0]
            received = b''

            try:
                line = line.decode("utf-8")
            except Exception as e:
                pass

            if line == CMD_PROCESSED_SUCCESSFULLY_MSG:
                CMD_PROCESSED_EVENT.set()
            elif line == CMD_PROCESSING_FAILURE_MSG:
                CMD_PROCESSED_EVENT.set()
            elif line == STATUS_START_MSG:
                status = Status()
                status.update_status(connection)
                print(status)
            elif line == SETUP_DONE_MSG:
                print("SETUP DONE")
            elif line == UNRECOGNIZED_CMD_MSG:
                # TODO implement resyncing if necessary
                print("NEEDS RESYNC")
                pass
            else:
                print("serial:", line)
        except Exception as e:
            print("stopped reading from serial because:", e)
            time.sleep(1)
            continue


def encode_int(val: int):
    return val.to_bytes(4, 'little', signed=True)


def encode_float(val: float):
    return struct.pack("<f", val)


def write_command(serial: serial.Serial, cmd: bytes):
    serial.write(b'<<<' + cmd + b'>>>')


def find_serial_port():
    default = '/dev/cu.usbserial-0001'
    devices = os.listdir('/dev/')
    for device in devices:
        if device.startswith(('serial', 'ttyACM', 'ttyUSB', 'ttyS', 'cu.usbserial')):
            return '/dev/' + device
    return default
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

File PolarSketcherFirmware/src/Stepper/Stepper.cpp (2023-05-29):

#include "Arduino.h"
#include "Stepper.h"

Stepper::Stepper(int _stepPin, int _dirPin)
{
    stepPin = _stepPin;
    dirPin = _dirPin;
    currentPosition = 0;
    targetPosition = 0;

    pinMode(stepPin, OUTPUT);
    pinMode(dirPin, OUTPUT);
}

Stepper::~Stepper() {}

void Stepper::setPosition(long position)
{
    currentPosition = position;
}

// setSpeed sets the speed in steps per second
int Stepper::setSpeed(int speed)
{
    if (speed > maxSpeed)
    {
        speed = maxSpeed;
    }

    if (speed <= 0)
    {
        speed = 1; // avoid division by zero
    }

    currentSpeed = speed;
    timeBetweenStepsMicros = (1.0 / currentSpeed) * 1000000;
    return currentSpeed;
}

int Stepper::getCurrentSpeed()
{
    return currentSpeed;
}

void Stepper::setTargetPosition(long position)
{
    targetPosition = position;
}

// stepTowardTarget is meant to be called once in every loop
// the function will check if it should actually take a step or not
bool Stepper::stepTowardTarget()
{
    if (currentPosition == targetPosition)
    {
        return false;
    }

    // check if stepper should make a step
    unsigned long nowMicros = micros();
    unsigned long elapsedTimeMicros = nowMicros - lastStepTimestampMicros;
    if (elapsedTimeMicros >= timeBetweenStepsMicros)
    {
        singleStepTowardTarget();
        lastStepTimestampMicros = nowMicros;
        return true;
    }

    return false;
}

void Stepper::singleStepTowardTarget()
{
    singleStep(currentPosition < targetPosition);
}

bool Stepper::singleStepAtSpeed(bool forward)
{
    // check if stepper should make a step
    unsigned long nowMicros = micros();
    unsigned long elapsedTimeMicros = nowMicros - lastStepTimestampMicros;
    if (elapsedTimeMicros >= timeBetweenStepsMicros)
    {
        singleStep(forward);
        lastStepTimestampMicros = nowMicros;
        return true;
    }

    return false;
}

void Stepper::singleStep(bool forward)
{
    setDir(forward);
    digitalWrite(stepPin, HIGH);
    delayMicroseconds(50);
    digitalWrite(stepPin, LOW);
    delayMicroseconds(50);

    currentPosition += forward ? 1 : -1;
}

void Stepper::setDir(bool forward)
{
    digitalWrite(dirPin, forward ? HIGH : LOW);
    goingForward = forward;
}

/*
void Stepper::write(int a, int b, int c, int d)
{
    digitalWrite(a, a);
    digitalWrite(b, b);
    digitalWrite(c, c);
    digitalWrite(d, d);
}

void Stepper::forward()
{
    write(1, 1, 0, 0);
    delayMicroseconds(2000);
    write(0, 1, 1, 0);
    delayMicroseconds(2000);
    write(0, 0, 1, 1);
    delayMicroseconds(2000);
    write(1, 0, 0, 1);
    delayMicroseconds(2000);
}

void Stepper::backward()
{
    write(1, 0, 0, 1);
    delayMicroseconds(2000);
    write(0, 0, 1, 1);
    delayMicroseconds(2000);
    write(0, 1, 1, 0);
    delayMicroseconds(2000);
    write(1, 1, 0, 0);
    delayMicroseconds(2000);
}
*/

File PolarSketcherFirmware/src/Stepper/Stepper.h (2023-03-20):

#ifndef STEPPER_H
#define STEPPER_H

class Stepper
{
private:
    int stepPin;
    int dirPin;
    bool goingForward = true;
    long currentPosition = 0;
    int targetPosition;
    int currentSpeed = 0;          // current set speed for stepper in steps per second
    int maxSpeed = 50000;          // max speed of this stepper is 500 steps per second
    int stepsPerRevolution = 200;  // total number of steps per revolution
    unsigned long lastStepTimestampMicros;
    unsigned long timeBetweenStepsMicros;


    void setDir(bool dir);
public:
    Stepper(int stepPin=0, int dirPin=0);
    ~Stepper();

    long getPosition() { return currentPosition; }
    long getTargetPosition() { return targetPosition; }

    void setPosition(long position);
    int setSpeed(int speed);
    int getCurrentSpeed();

    bool stepTowardTarget();
    void singleStepTowardTarget();
    void singleStep(bool forward);
    bool singleStepAtSpeed(bool forward);
    void setTargetPosition(long position);
};

#endif

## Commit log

2021-09-04 fixes simulator and removes pygame from server and adds slider
    [dryrun_drawer.py, simulator.py]
2021-09-05 uses thread instead of process and fixes a blocking issue in the BE
    [dryrun_drawer.py]
2021-09-13 implemented zigzag toolpath generation and fixed some bugs
    [dryrun_drawer.py, toolpath_generation.py]
2021-09-14 fixes a an issue in the toolpath generation by detecting if the intersected paths are the same for the next line
    [dryrun_drawer.py, svg_drawer.py, toolpath_generation.py]
2021-09-19 fixes drawing when bbox is bigger than viewbox
    [dryrun_drawer.py, simulator.py, sort_paths.py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]
2021-10-14 integrates tailwind + fixes some UI bugs + little makeover
    [dryrun_drawer.py, toolpath_generation.py]
2021-10-15 adds maxout button and fixes a few more bugs
2021-10-22 fixes rendering size and rotation
    [dryrun_drawer.py, toolpath_generation.py]
2022-11-07 major code cleanup and fixes all around
    [path_quadtree.py, simulator.py, sort_paths.py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]
2023-02-17 adds PolarSketcherFirmware for esp32 created with Platformio
2023-02-23 fixes pen position bugs. Polar sketcher corrects angle position
    [main.cpp, main.py, path_generator.py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]
2023-02-23 fixes not setting offset
    [path_generator.py]
2023-03-07 fix RX buffer overflow and pen not lifting when path is not closed
    [main.cpp, path_generator.py]
2023-03-20 fix couple bug and improve position correction
    [Stepper.h, main.cpp, main.py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]
2023-03-22 fix the position overflow problem; fix frontend illustration
    [main.cpp, main.py, polar_sketcher_interface.py]
2023-03-26 fixes measurements and angle position correction, also improves accuracy by generating more points
    [main.cpp, main.py, path_generator.py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]
2023-04-03 support for standard paper sizes and boundary drawing fix
    [path_generator.py]
2023-05-29 implement incremental error correction
    [Stepper.cpp, main.cpp, main.py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]
2023-08-05 error correction routine improvement. paths close properly
    [main.cpp, polar_sketcher_interface.py]
2023-08-13 fix flask-sockets bug
2023-08-13 fix Dockerfile for raspberrypi and use opencv headless
2023-09-02 shorten the ACK messages + dynamic serial port finding
    [main.cpp, polar_sketcher_interface.py]
2023-09-02 fix path sort algorithm by using reversed() instead of reverse()
    [sort_paths.py]
2023-09-02 fix build for raspberrypi
2023-09-02 fix incorrect opening of serial port
    [polar_sketcher_interface.py]
2023-09-16 makes polar sketcher only send 1 byte per loop at maximum, making the motors stall less and be more silent
    [main.cpp, polar_sketcher_interface.py]
2023-10-31 comitting missing firmware communicator
    [communicator.py]
2023-10-31 comitting kicad pcb files
    [polar_sketcher.csv, polar_sketcher.kicad_pcb, polar_sketcher.kicad_sch]
2023-10-31 fix bug in plotter communication
    [main.cpp, polar_sketcher_interface.py]
2023-11-01 remove waiting for startup message because raspberrypi always misses it
2023-11-01 fix faulty int64_t type
    [main.cpp]
2023-11-01 waits on setup done again, fixes bug of unnecessary pen lifting
    [communicator.py, main.cpp, polar_sketcher_interface.py]
2023-11-02 more bugfixes in the polar_sketcher_consumer
    [main.cpp, polar_sketcher_interface.py]
2023-11-05 generate paths in a thread, allowing the server thread to multiplex for efficiently. Fixes blocking on abort.
    [main.cpp, main.py, path_generator.py]
2023-11-05 add threaded approach to regular paths too, clean refactor of feature
2023-11-05 add feature to enable angle correction by config
    [main.cpp, main.py, polar_sketcher_interface.py]
2023-11-05 fixes bad parameter parsing
    [main.py]
2023-11-05 fix early return bug in threaded path generation
    [path_generator.py]
2023-11-06 adds the constant multiplier back, movement was too jittery for plotter. more bug fixes.
    [main.cpp, path_generator.py, polar_sketcher_interface.py]
2023-11-11 clean up the angle correction routine
    [main.cpp]
2023-11-11 update calibration values
2023-11-12 uses a more chill angle correction algorithm
    [main.cpp]
2023-11-12 change default threaded_generation queue size to avoid plotter from stopping
    [path_generator.py]
2023-11-21 add 'serial' as key prefix to look for in devices. Especially made for raspberrypi when communicating over GPIO pins
2023-11-22 add info on how to upload firmware directly from the raspberry pi
2023-11-22 small fixes in the enable motor logic
    [main.cpp]
2023-11-26 add all models for current version of polar plotter
    [AngleLimitSwitch.stl, Carriage.stl, EncoderHousingBottom.stl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]
2023-12-02 fix design flaw in PCB that makes it fry the esp32 if you connect the encoder the opposite way around
    [polar_sketcher.kicad_pcb, polar_sketcher.kicad_sch]
2023-12-02 update calibration values with values from the drv8825 driver
2023-12-02 removing reset sequence because its not working on the new esp32
    [polar_sketcher_interface.py]
2023-12-03 new calibration values
2023-12-03 Revert "new calibration values"
    This reverts commit 4d135bc593fd306e36c73a562f358e138e867b85.
    [communicator.py, polar_sketcher_interface.py]
